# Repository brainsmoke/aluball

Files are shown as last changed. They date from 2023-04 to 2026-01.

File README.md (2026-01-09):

# aluball

White LED lamp made with aluminium PCBs

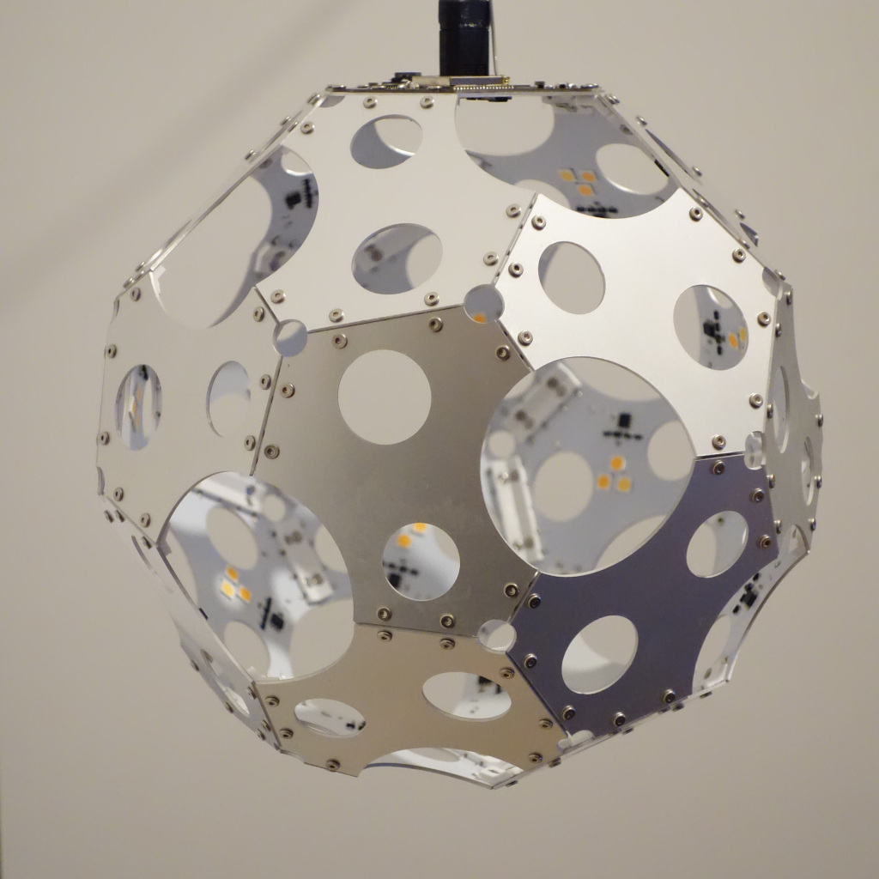
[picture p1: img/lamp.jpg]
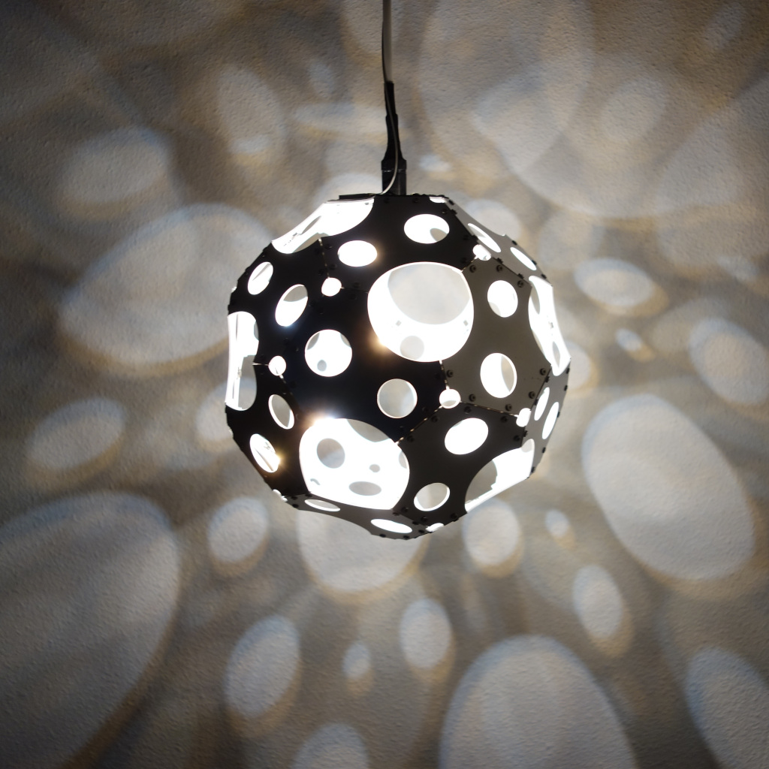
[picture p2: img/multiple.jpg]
|  |  |
|-|-|
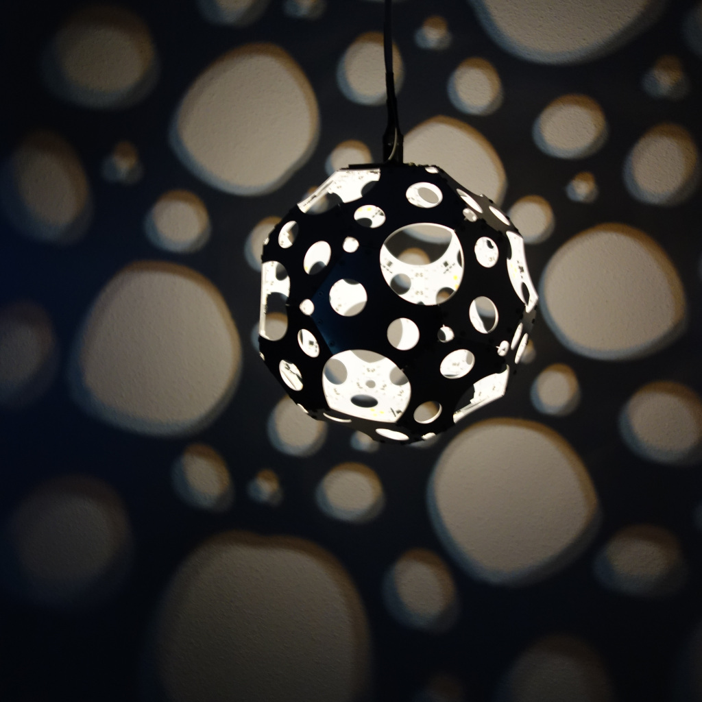
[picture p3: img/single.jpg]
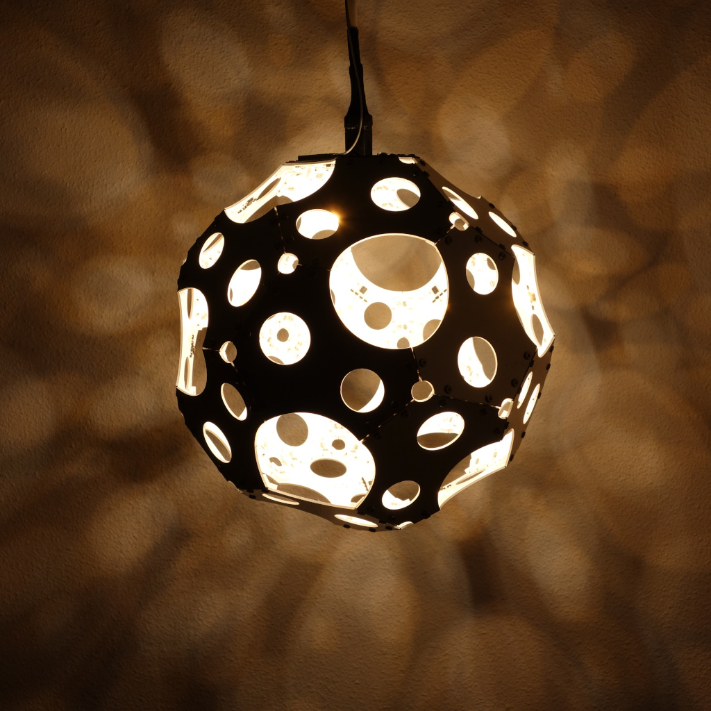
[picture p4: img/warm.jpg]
|  |  |
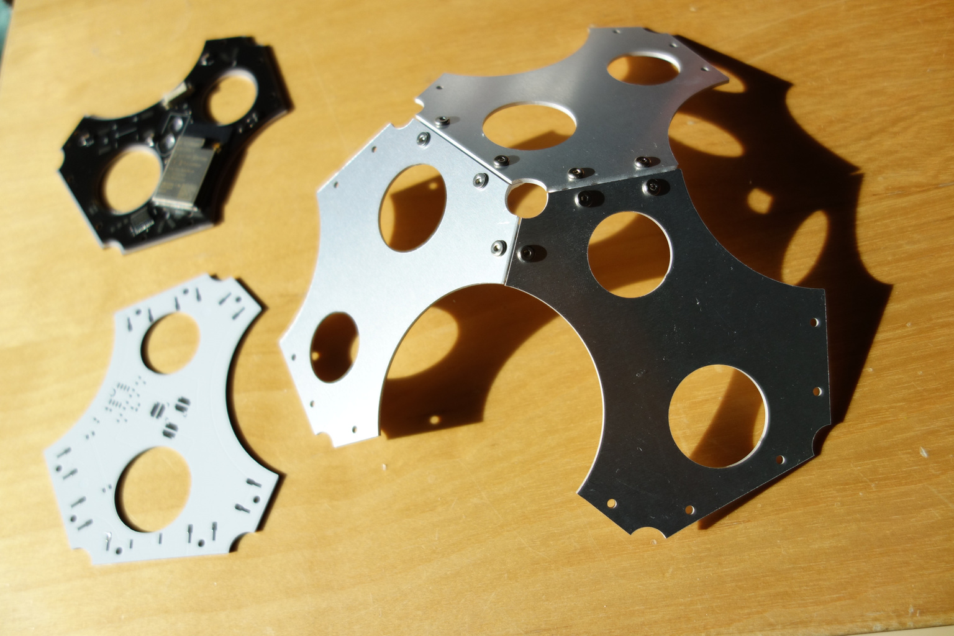
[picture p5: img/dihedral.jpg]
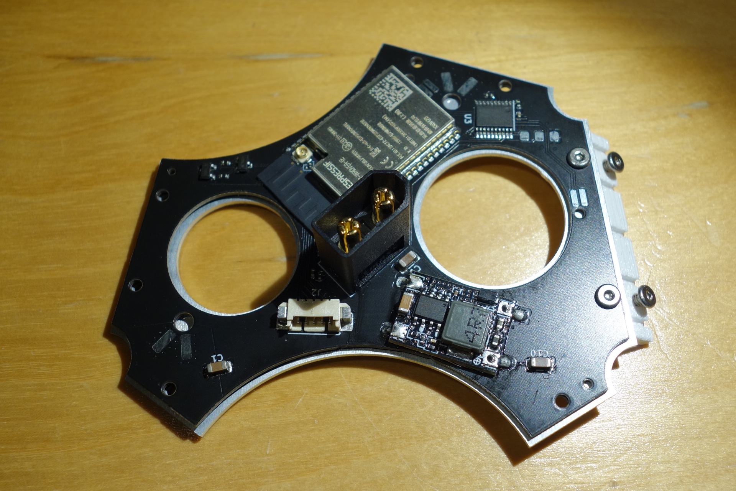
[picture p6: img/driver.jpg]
|  |  |
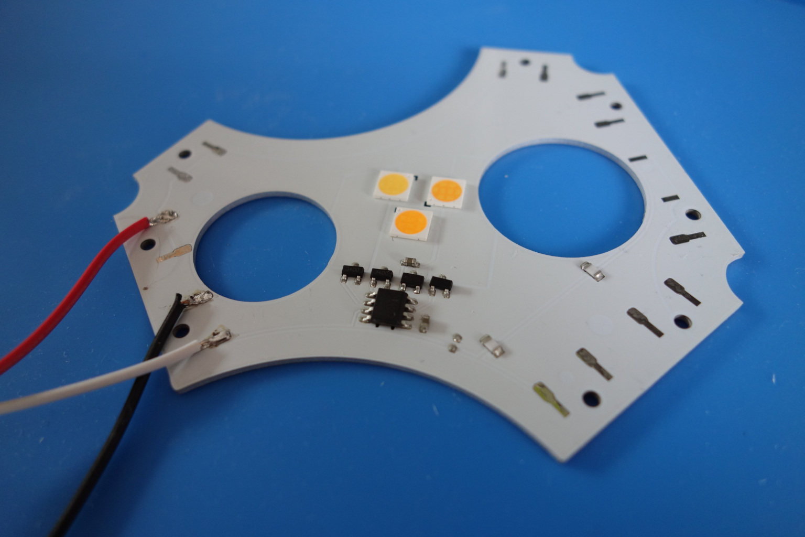
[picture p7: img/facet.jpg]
|  | |

# software

https://github.com/brainsmoke/leddriver3d

## ESP32

https://github.com/brainsmoke/leddriver3d/tree/master/firmware/esp32

Edit `fs/conf/model.json:`

```
{
	"model": "/models/aluball"
}
```

## STM32

https://github.com/brainsmoke/leddriver3d/blob/master/firmware/stm32/uartball16/uartball16.bin

## PADAUK

https://github.com/brainsmoke/leddriver3d/tree/master/firmware/pdk/softpwm

`./write.sh <address>` 3x for each in 0..7

Use the mapping in https://github.com/brainsmoke/aluball/blob/main/map.svg

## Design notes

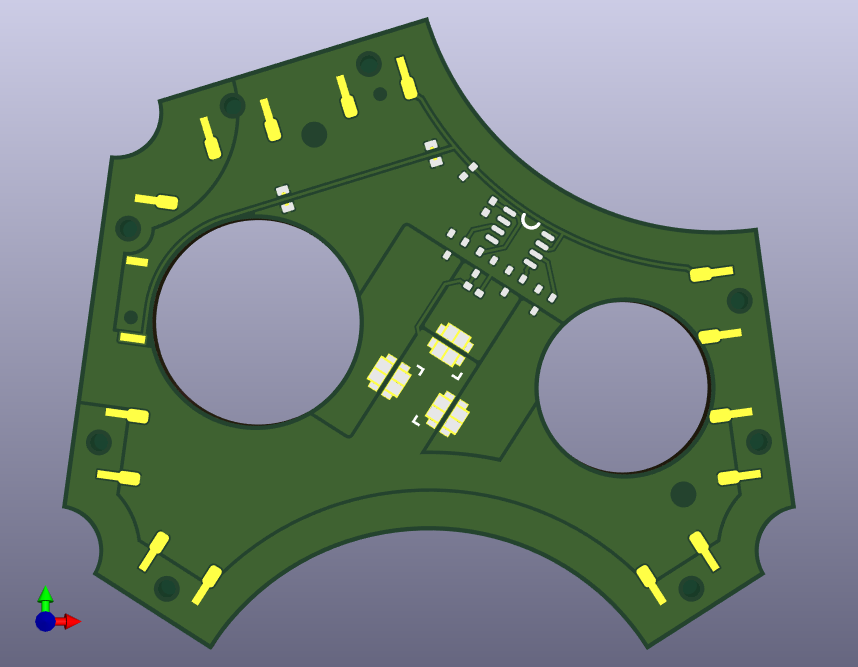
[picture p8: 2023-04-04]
pcb/driver_v1/alu.png

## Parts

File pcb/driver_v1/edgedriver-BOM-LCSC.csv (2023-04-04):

Comment | Designator | Footprint | LCSC Part Number
10uF | C4,C2,C9 | 0603 | C19702
1uF | C7,C6,C1 | 0603 | C15849
100nF | C8,C5,C3 | 0603 | C14663
AO3400 | Q1,Q2 | SOT-23-3L | C20917
1k | R1 | 0603 | C21190
10k | R6,R7,R3,R4,R5,R2 | 0603 | C25804
STM32F030F4P6 | U2 | TSSOP-20_4.4x6.5x0.65P | C89040
AMS1117-3.3 | U3 | SOT-223 | C6186
CP2104 | U4 | QFN-24_EP_4.0x4.0x0.5P | C47742

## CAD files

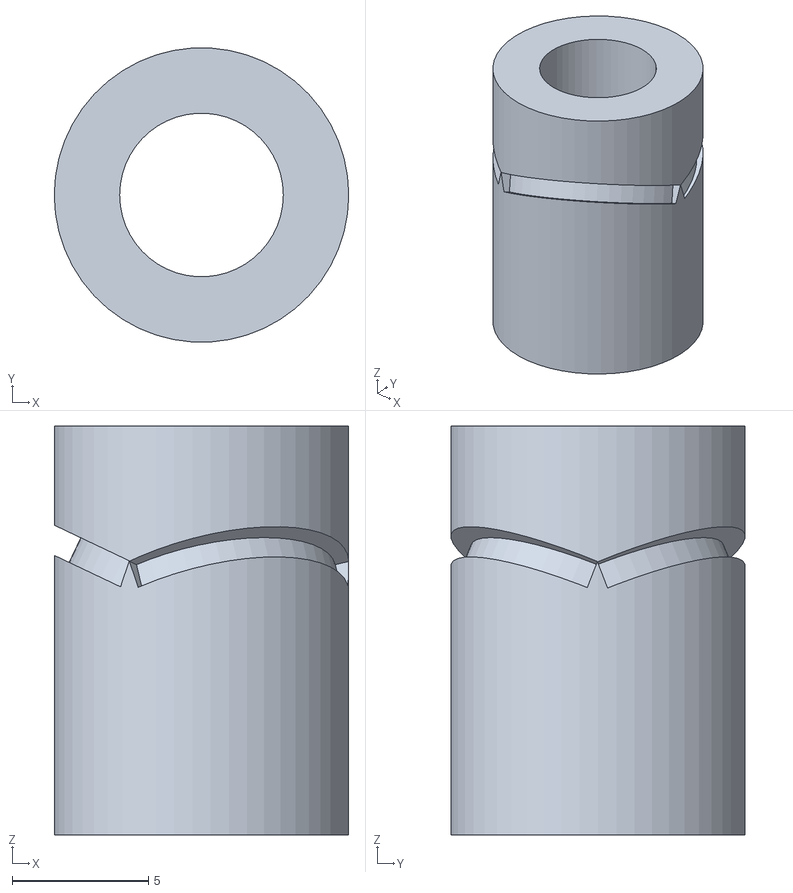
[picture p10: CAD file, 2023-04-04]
scad/funnel.stl
10.8 x 10.8 x 15.0

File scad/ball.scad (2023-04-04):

use <facet.scad>;

module ball(r,t) {
multmatrix (m=[[-2.333238e-16,1.000000e+00,0.000000e+00,0.000000e+00],[1.000000e+00,2.333238e-16,0.000000e+00,0.000000e+00],[-0.000000e+00,0.000000e+00,-1.000000e+00,0.000000e+00],[0, 0, 0, 1]]) {facet(r,t);};

multmatrix (m=[[-8.874907e-01,-4.512340e-01,-9.353135e-02,0.000000e+00],[-2.718445e-01,6.765287e-01,-6.844044e-01,0.000000e+00],[3.721032e-01,-5.819766e-01,-7.230785e-01,0.000000e+00],[0, 0, 0, 1]]) {facet(r,t);};
multmatrix (m=[[6.765287e-01,-4.512340e-01,5.819766e-01,0.000000e+00],[-2.718445e-01,-8.874907e-01,-3.721032e-01,0.000000e+00],[6.844044e-01,9.353135e-02,-7.230785e-01,0.000000e+00],[0, 0, 0, 1]]) {facet(r,t);};
multmatrix (m=[[2.142081e-01,9.317418e-01,-2.932100e-01,0.000000e+00],[-9.762468e-01,2.142081e-01,-3.251364e-02,0.000000e+00],[3.251364e-02,2.932100e-01,9.554950e-01,0.000000e+00],[0, 0, 0, 1]]) {facet(r,t);};
multmatrix (m=[[7.727930e-01,-5.831169e-01,2.505306e-01,0.000000e+00],[4.325578e-01,7.727930e-01,4.644187e-01,0.000000e+00],[-4.644187e-01,-2.505306e-01,8.494408e-01,0.000000e+00],[0, 0, 0, 1]]) {facet(r,t);};
multmatrix (m=[[-7.760392e-01,-4.461569e-01,-4.457659e-01,0.000000e+00],[8.737803e-02,-7.760392e-01,6.246025e-01,0.000000e+00],[-6.246025e-01,4.457659e-01,6.412211e-01,0.000000e+00],[0, 0, 0, 1]]) {facet(r,t);};
multmatrix (m=[[7.430105e-02,-9.898459e-01,1.211790e-01,0.000000e+00],[-4.563110e-01,7.430105e-02,8.867128e-01,0.000000e+00],[-8.867128e-01,-1.211790e-01,-4.461569e-01,0.000000e+00],[0, 0, 0, 1]]) {facet(r,t);};
multmatrix (m=[[2.885092e-01,3.693766e-01,-8.833592e-01,0.000000e+00],[-4.325578e-01,-7.727930e-01,-4.644187e-01,0.000000e+00],[-8.541992e-01,5.160929e-01,-6.318117e-02,0.000000e+00],[0, 0, 0, 1]]) {facet(r,t);};
multmatrix (m=[[1.738115e-01,5.674422e-01,8.048595e-01,0.000000e+00],[-2.718445e-01,8.131897e-01,-5.146097e-01,0.000000e+00],[-9.465147e-01,-1.293516e-01,2.955977e-01,0.000000e+00],[0, 0, 0, 1]]) {facet(r,t);};
multmatrix (m=[[-2.885092e-01,-9.418959e-01,1.720310e-01,0.000000e+00],[4.325578e-01,-2.885092e-01,-8.541992e-01,0.000000e+00],[8.541992e-01,-1.720310e-01,4.906619e-01,0.000000e+00],[0, 0, 0, 1]]) {facet(r,t);};
multmatrix (m=[[-1.738115e-01,6.649743e-01,7.263599e-01,0.000000e+00],[2.718445e-01,-6.765287e-01,6.844044e-01,0.000000e+00],[9.465147e-01,3.164143e-01,-6.318117e-02,0.000000e+00],[0, 0, 0, 1]]) {facet(r,t);};
multmatrix (m=[[-7.430105e-02,3.299486e-01,-9.410703e-01,0.000000e+00],[4.563110e-01,8.503402e-01,2.621103e-01,0.000000e+00],[8.867128e-01,-4.099456e-01,-2.137404e-01,0.000000e+00],[0, 0, 0, 1]]) {facet(r,t);};
multmatrix (m=[[-8.503402e-01,3.299486e-01,4.099456e-01,0.000000e+00],[-4.563110e-01,-8.503402e-01,-2.621103e-01,0.000000e+00],[2.621103e-01,-4.099456e-01,8.736377e-01,0.000000e+00],[0, 0, 0, 1]]) {facet(r,t);};
multmatrix (m=[[8.131897e-01,5.674422e-01,1.293516e-01,0.000000e+00],[-2.718445e-01,1.738115e-01,9.465147e-01,0.000000e+00],[5.146097e-01,-8.048595e-01,2.955977e-01,0.000000e+00],[0, 0, 0, 1]]) {facet(r,t);};
multmatrix (m=[[-7.754719e-02,-4.855849e-01,-8.707432e-01,0.000000e+00],[9.762468e-01,-2.142081e-01,3.251364e-02,0.000000e+00],[-2.023084e-01,-8.475389e-01,4.906619e-01,0.000000e+00],[0, 0, 0, 1]]) {facet(r,t);};
multmatrix (m=[[8.874907e-01,5.077025e-03,-4.607976e-01,0.000000e+00],[2.718445e-01,-8.131897e-01,5.146097e-01,0.000000e+00],[-3.721032e-01,-5.819766e-01,-7.230785e-01,0.000000e+00],[0, 0, 0, 1]]) {facet(r,t);};
multmatrix (m=[[-6.765287e-01,6.649743e-01,-3.164143e-01,0.000000e+00],[2.718445e-01,-1.738115e-01,-9.465147e-01,0.000000e+00],[-6.844044e-01,-7.263599e-01,-6.318117e-02,0.000000e+00],[0, 0, 0, 1]]) {facet(r,t);};
multmatrix (m=[[2.022668e-16,-2.137404e-01,9.768905e-01,0.000000e+00],[-1.000000e+00,-5.833095e-17,1.942890e-16,0.000000e+00],[1.545554e-17,-9.768905e-01,-2.137404e-01,0.000000e+00],[0, 0, 0, 1]]) {facet(r,t);};
multmatrix (m=[[7.760392e-01,-3.401027e-01,-5.311246e-01,0.000000e+00],[-8.737803e-02,7.760392e-01,-6.246025e-01,0.000000e+00],[6.246025e-01,5.311246e-01,5.725193e-01,0.000000e+00],[0, 0, 0, 1]]) {facet(r,t);};
multmatrix (m=[[-2.142081e-01,-4.855849e-01,8.475389e-01,0.000000e+00],[9.762468e-01,-7.754719e-02,2.023084e-01,0.000000e+00],[-3.251364e-02,8.707432e-01,4.906619e-01,0.000000e+00],[0, 0, 0, 1]]) {facet(r,t);};
multmatrix (m=[[-7.727930e-01,3.693766e-01,-5.160929e-01,0.000000e+00],[-4.325578e-01,2.885092e-01,8.541992e-01,0.000000e+00],[4.644187e-01,8.833592e-01,-6.318117e-02,0.000000e+00],[0, 0, 0, 1]]) {facet(r,t);};
multmatrix (m=[[-8.131897e-01,5.077025e-03,5.819766e-01,0.000000e+00],[2.718445e-01,8.874907e-01,3.721032e-01,0.000000e+00],[-5.146097e-01,4.607976e-01,-7.230785e-01,0.000000e+00],[0, 0, 0, 1]]) {facet(r,t);};
multmatrix (m=[[7.754719e-02,-7.468317e-01,-6.604762e-01,0.000000e+00],[-9.762468e-01,7.754719e-02,-2.023084e-01,0.000000e+00],[2.023084e-01,6.604762e-01,-7.230785e-01,0.000000e+00],[0, 0, 0, 1]]) {facet(r,t);};
multmatrix (m=[[8.503402e-01,3.299486e-01,4.099456e-01,0.000000e+00],[4.563110e-01,-7.430105e-02,-8.867128e-01,0.000000e+00],[-2.621103e-01,9.410703e-01,-2.137404e-01,0.000000e+00],[0, 0, 0, 1]]) {facet(r,t);};
}
ball(100, 1);

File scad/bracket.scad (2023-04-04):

d=.001;

module screw_hole(pos, depth, drill, nut)
{
	x = pos[0];
	y = pos[1];

	translate([x,y,-d/2])
	union()
	{
		cylinder(depth+d, drill/2);
		translate( [0,0,depth-1.5] )
			cylinder(depth, nut/2, nut/2, $fn=6);
	}
}

module plate(length, width, depth)
{
	translate([-length/2,0,0])
		cube([length, width, depth]);
}

module plate_holes(length, width, depth, holes, drill, nut, slits, slitwidth)
{
	translate([-length/2,0,0])
	{
		for (pos = holes)
			screw_hole(pos, depth, drill, nut);

		for (l = slits)
			translate([l-slitwidth/2,-d/2,-d])
				cube([slitwidth, width+d, slitwidth+d]);
	}
}

module angle_bracket(length, width, depth, dihedral, holes, drill, nut, slits, slitwidth)
{
	difference() {
		for(i = [-1,1] )
			rotate([ 90-dihedral/2,0,i*90])
				plate(length, width, depth);

		for(i = [-1,1] )
		{
			slits_side = concat( slits,  [ for (s = slits) (length-s) ]);
			rotate([ (180-dihedral)/2,0,i*90])
				plate_holes(length, width, depth, holes, drill, nut, slits_side, slitwidth);
		}
	}
}

dihedral_angle=136.30923289232;
rotate([ 0,90-dihedral_angle/2,0 ])
angle_bracket(16.30,          /* length        */
              6,              /* width         */
              2.5,            /* depth         */
              dihedral_angle, /* angle         */
              [               /* list of holes */
                [2.5,3.2],
                [16.30-2.5,3.2]
              ],
              2,              /* hole diameter (per printer tweaking) */
              4.5,            /* nut diameter (same)                  */
              [6],            /* slits (symmetrical) :-(              */
              1.3,            /* width/height of slits                */
              $fn=20);

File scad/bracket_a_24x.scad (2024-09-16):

use <facet.scad>;
rotate([180,0,0])
ball_bracket(1,100);

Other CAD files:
scad/bracket_b_24x.scad
scad/bracket_c_12x.scad
scad/facet.scad
scad/funnel.scad
scad/screw.scad

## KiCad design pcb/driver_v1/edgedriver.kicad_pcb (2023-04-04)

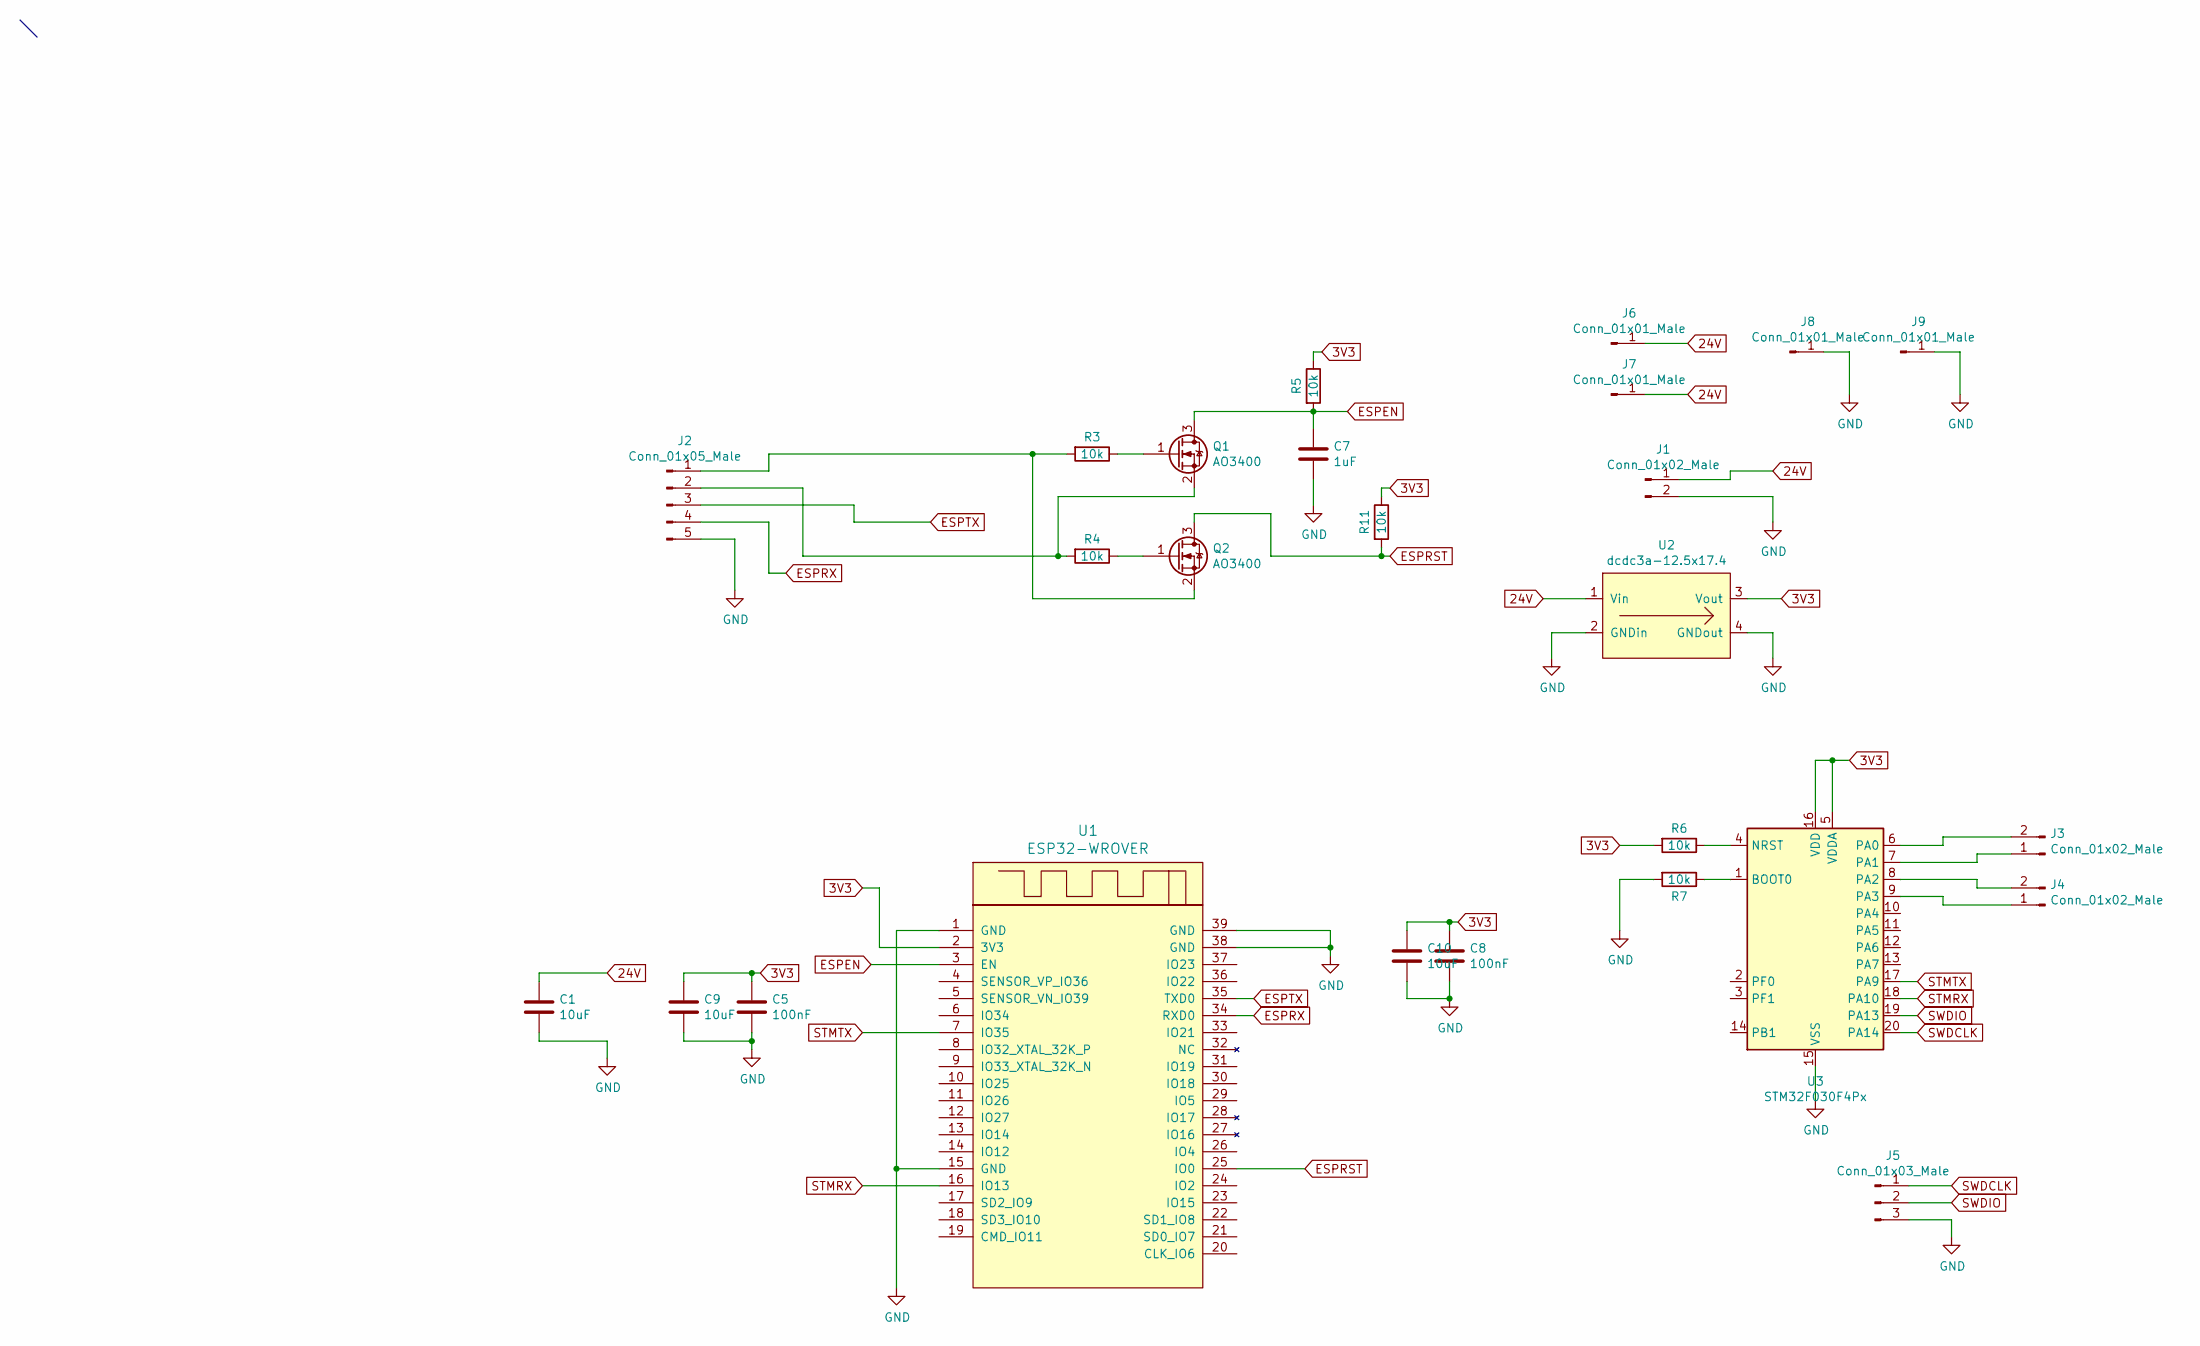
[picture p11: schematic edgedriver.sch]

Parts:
C1, C9, C10: 10uF; C_1206_3216Metric; LCSC C13585
C5, C8: 100nF; C_0402_1005Metric; LCSC C1525
C7: 1uF; C_0402_1005Metric; LCSC C52923
J1: Conn_01x02_Male; xt60-pcb
J2: Conn_01x05_Male; Molex_PicoBlade_53261-0571_1x05-1MP_P1.25mm_Horizontal; LCSC C225114
J3, J4: Conn_01x02_Male; PinHeader_1x02_P2.54mm_Vertical
J5: Conn_01x03_Male; PinHeader_1x03_P2.54mm_Vertical
J6, J7, J8, J9: Conn_01x01_Male; solderpad1
Q1, Q2: AO3400; SOT-23; LCSC C20917
R3, R4, R5, R6, R7, R11: 10k; R_0402_1005Metric; LCSC C25744
U1: ESP32-WROVER; XCVR_ESP32-WROVER; LCSC C701352
U2: dcdc3a-12.5x17.4
U3: STM32F030F4Px; TSSOP-20_4.4x6.5mm_P0.65mm; LCSC C89040

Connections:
3V3: C5.1, C8.1, C9.1, C10.1, R5.1, R6.2, R11.1, U1.2 (3V3), U2.3 (Vout), U3.5 (VDDA), U3.16 (VDD)
24V: C1.1, J1.1, J6.1, J7.1, U2.1 (Vin)
ESPEN: C7.1, Q1.3 (D), R5.2, U1.3 (EN)
ESPRST: Q2.3 (D), R11.2, U1.25 (IO0)
ESPRX: J2.4, U1.34 (RXD0)
ESPTX: J2.3, U1.35 (TXD0)
GND: C1.2, C5.2, C7.2, C8.2, C9.2, C10.2, J1.2, J2.5, J5.3, J8.1, J9.1, R7.2, U1.1 (GND), U1.15 (GND), U1.38 (GND), U1.39 (GND), U2.2 (GNDin), U2.4 (GNDout), U3.15 (VSS)
unnamed: J2.1, Q2.2 (S), R3.2
unnamed: J2.2, Q1.2 (S), R4.2
unnamed: J3.1, U3.7 (PA1)
unnamed: J3.2, U3.6 (PA0)
unnamed: J4.1, U3.9 (PA3)
unnamed: J4.2, U3.8 (PA2)
unnamed: Q1.1 (G), R3.1
unnamed: Q2.1 (G), R4.1
unnamed: R6.1, U3.4 (NRST)
unnamed: R7.1, U3.1 (BOOT0)
STMRX: U1.16 (IO13), U3.18 (PA10)
STMTX: U1.7 (IO35), U3.17 (PA9)
SWDCLK: J5.1, U3.20 (PA14)
SWDIO: J5.2, U3.19 (PA13)

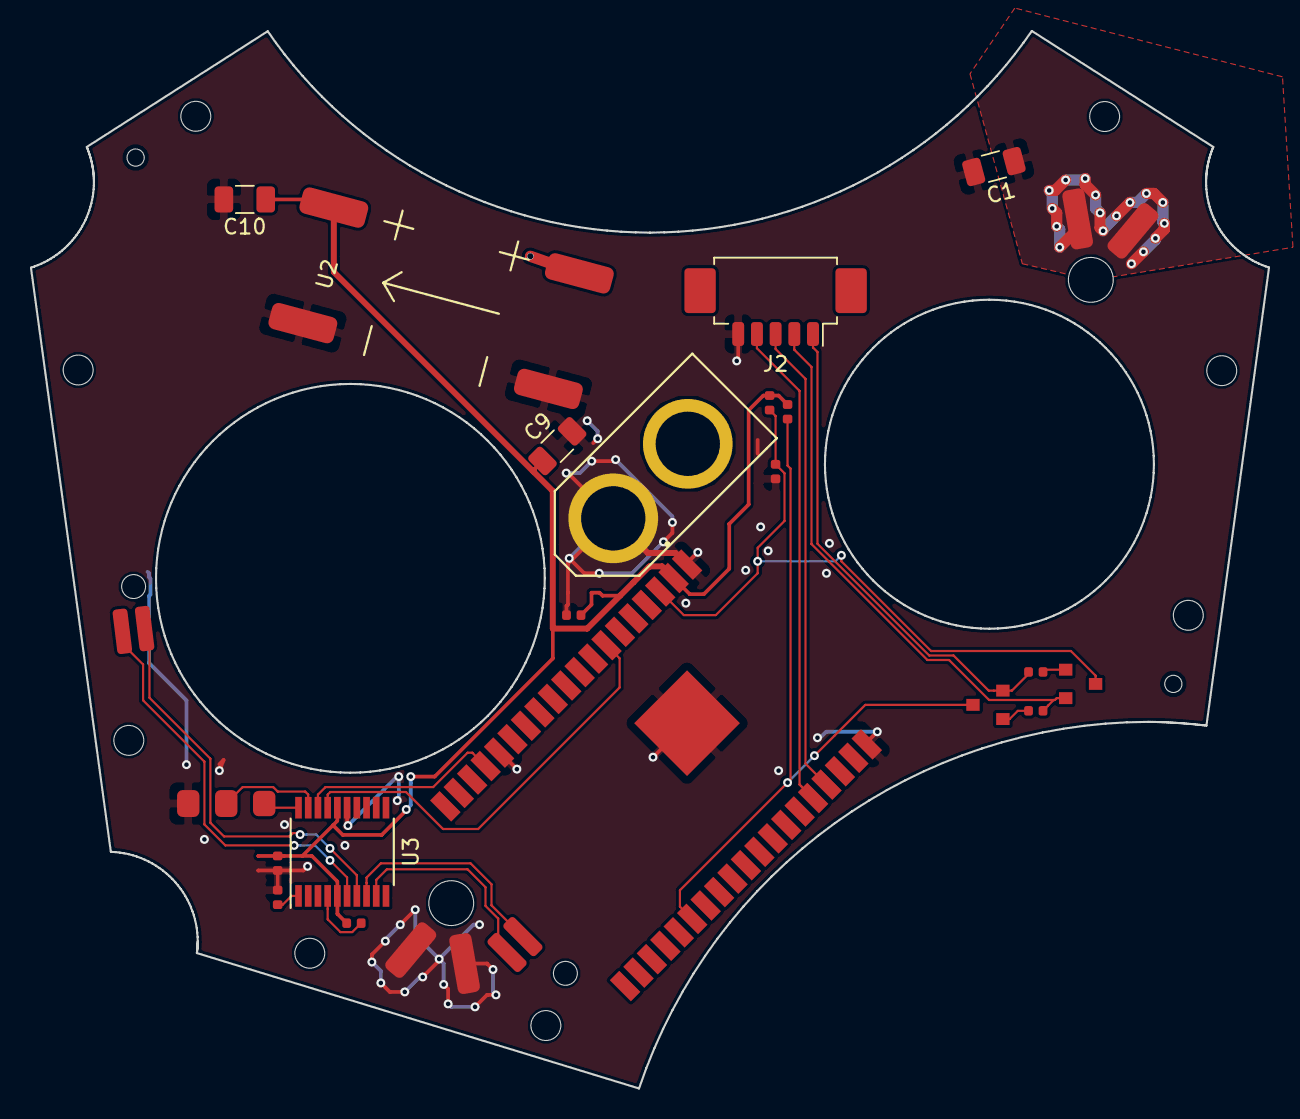
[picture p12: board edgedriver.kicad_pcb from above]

Board: 2 copper layers, 82.8 x 70.7 mm, 26 parts (0 on the bottom side), 21 nets.

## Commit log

2023-04-04 initial import
    [ball.scad, bracket.scad, bracket_a_24x.scad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]
2024-09-16 tweak sizes to work with my 3d-printer
    [facet.scad]
2024-09-16 rotate models to lay flat on a printer bed
    [bracket_a_24x.scad, bracket_b_24x.scad, bracket_c_12x.scad]
